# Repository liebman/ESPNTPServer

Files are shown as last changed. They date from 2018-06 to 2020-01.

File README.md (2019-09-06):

# ESPNTPServer

GPS fueled ESP8266 based NTP Server



[src](src) Contains the code for the NTP Server

[eagle](eagle) contains the schematic and board designs in Eagle cad.

[enclosure](enclosure) contains the STL files for the enclosure.

This is designed around [this GPS module](https://www.amazon.com/gp/product/B075DD5746/) but any module with standard NMEA output and a pult per second signal will work if you redesign the board or use an adapter.

I also used [this display module](https://www.amazon.com/gp/product/B00O2KDQBE/).  You can use others but be careful with the power polarity, I have modules where VCC and ground pins are in a different order.

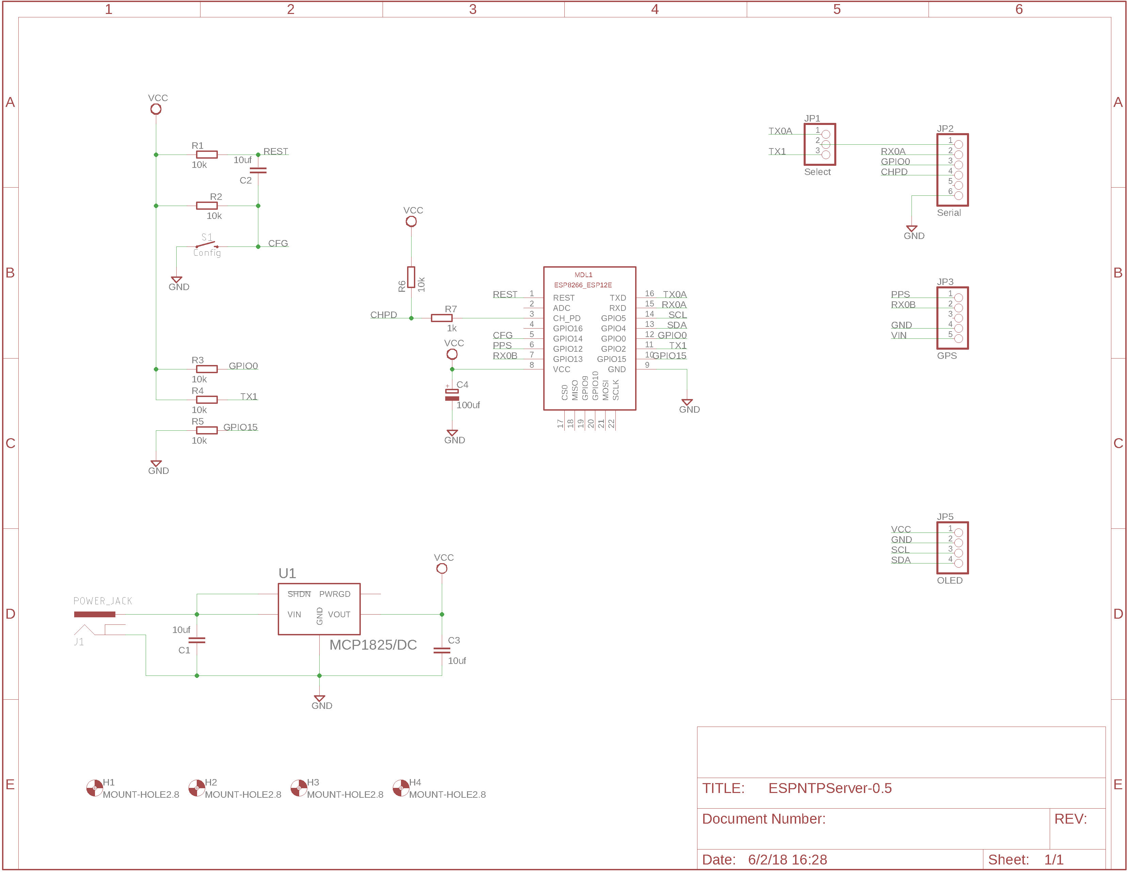
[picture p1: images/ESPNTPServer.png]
Schematic

assembly
running

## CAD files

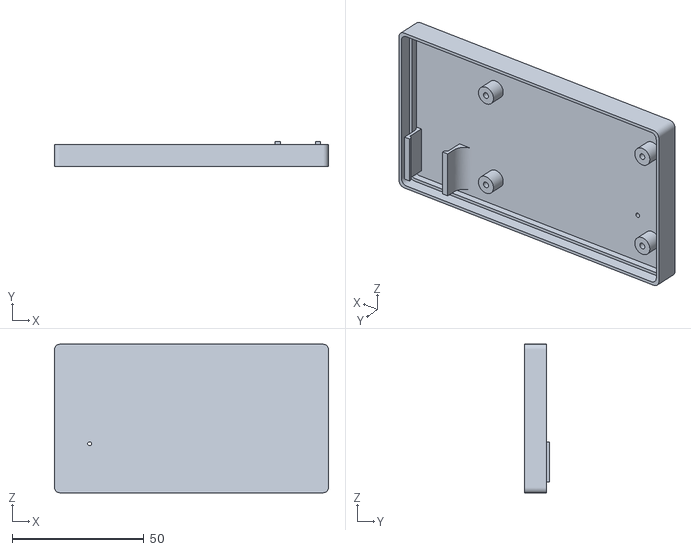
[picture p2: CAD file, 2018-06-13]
enclosure/Bottom-0.5v33.stl
103.8 x 9.30 x 56.3

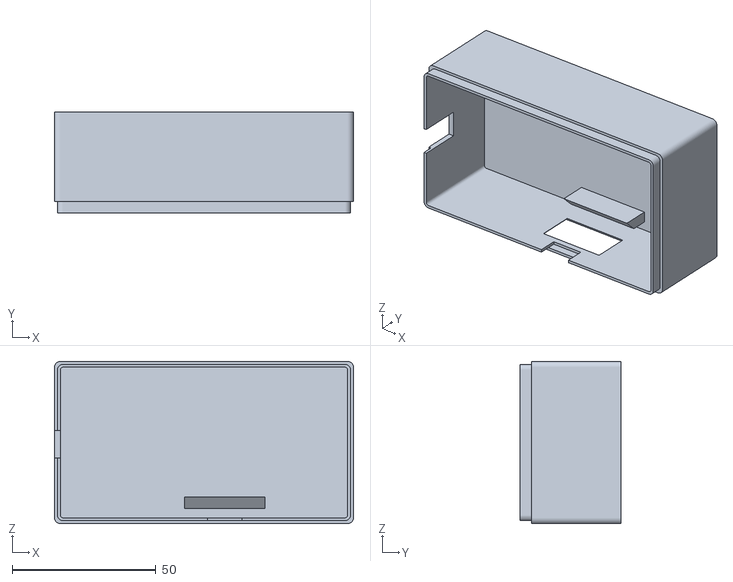
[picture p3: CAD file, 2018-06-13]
enclosure/Top-0.5v33.stl
103.8 x 35.0 x 56.3

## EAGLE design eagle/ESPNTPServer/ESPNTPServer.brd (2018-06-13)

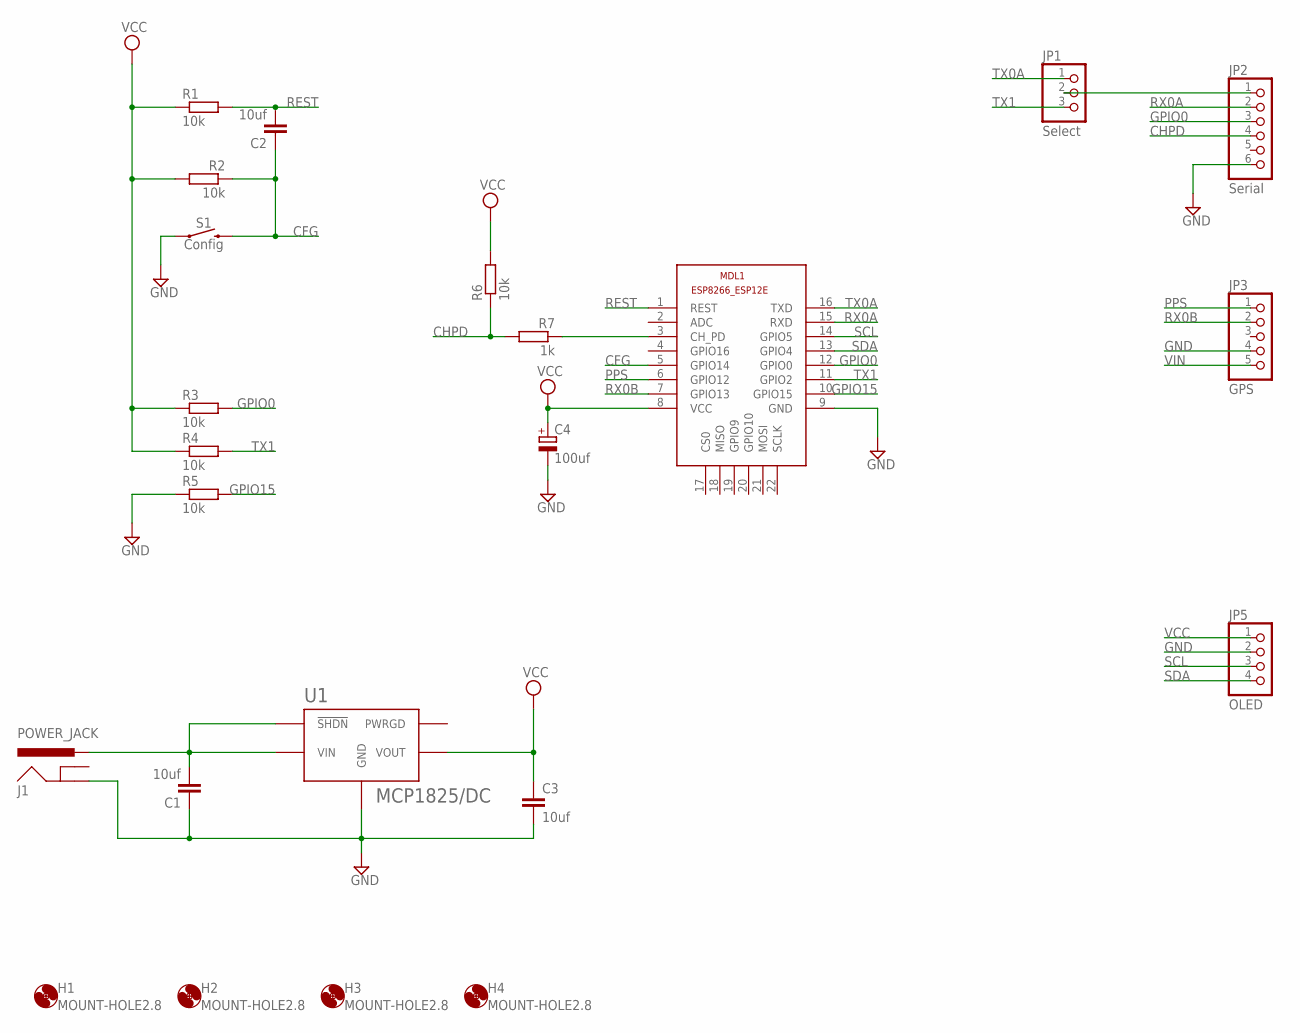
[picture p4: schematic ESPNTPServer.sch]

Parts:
C1, C2, C3: 10uf; C050-025X075
C4: 100uf; E2,5-5
H1, H2, H3, H4: MOUNT-HOLE2.8; 2,8
J1: POWER_JACK; POWER_JACK_PTH
JP1: Select; 1X03
JP2: Serial; 1X06
JP3: GPS; 1X05
JP5: OLED; 1X04
MDL1: ESP8266-12F; ESP8266-ESP12E
R1, R2, R3, R4, R5, R6: 10k; 0204V
R7: 1k; 0204V
S1: Config; TACTILE_SWITCH_PTH_6.0MM
U1: MCP1825/DC; SOT-223-5

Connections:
CFG: C2.1, MDL1.5 (GPIO14), R2.1, S1.3 (2)
CHPD: JP2.4, R6.1, R7.2
GND: C1.1, C3.2, C4.-, J1.GND, JP2.6, JP3.4, JP5.2, MDL1.9 (GND), R5.1, S1.1, U1.P$3 (GND), U1.P$6 (GND)
GPIO0: JP2.3, MDL1.12 (GPIO0), R3.2
GPIO15: MDL1.10 (GPIO15), R5.2
unnamed: JP1.2, JP2.1
unnamed: MDL1.3 (CH_PD), R7.1
PPS: JP3.1, MDL1.6 (GPIO12)
REST: C2.2, MDL1.1 (REST), R1.2
RX0A: JP2.2, MDL1.15 (RXD)
RX0B: JP3.2, MDL1.7 (GPIO13)
SCL: JP5.3, MDL1.14 (GPIO5)
SDA: JP5.4, MDL1.13 (GPIO4)
TX0A: JP1.1, MDL1.16 (TXD)
TX1: JP1.3, MDL1.11 (GPIO2), R4.2
VCC: C3.1, C4.+, JP5.1, MDL1.8 (VCC), R1.1, R2.2, R3.1, R4.1, R6.2, U1.P$4 (VOUT)
VIN: C1.2, J1.PWR, JP3.5, U1.P$1 (!SHDN), U1.P$2 (VIN)

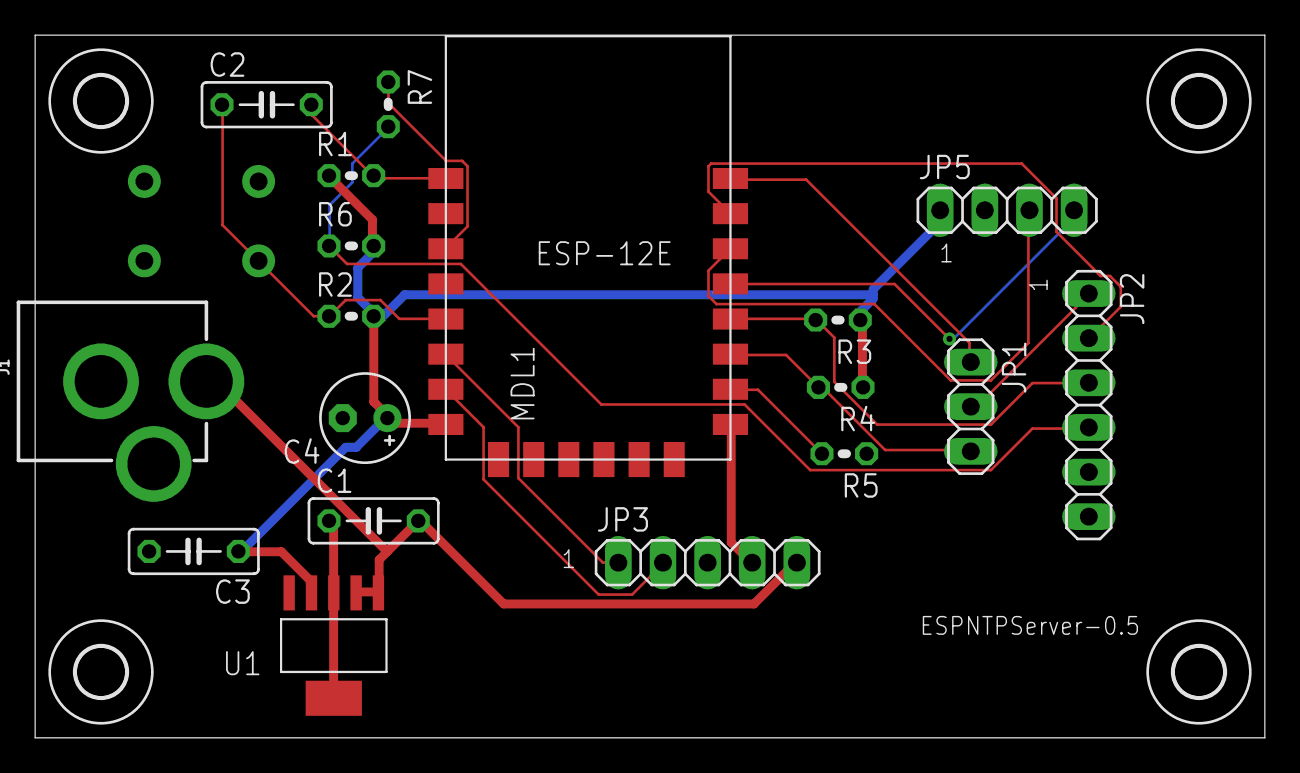
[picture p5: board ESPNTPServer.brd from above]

Board: 2 copper layers, 70.0 x 40.0 mm, 23 parts (1 on the bottom side), 17 nets.

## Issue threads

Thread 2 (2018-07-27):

Problem compiling in Arduino IDE

delinend, 2018-07-27:
Hi liebman.

I'm trying to compile you ESPNTPServer via Arduino IDE 1.8.1 (have maked an empty ESPNTPServer.ino file)
But I'm stranding on this error, in the ESPNTPServer.cpp:

sketch\ESPNTPServer.cpp: In function 'void logTimeFirst(DLogBuffer&, DLogLevel)':

ESPNTPServer.cpp:49: error: aggregate 'timeval tv' has incomplete type and cannot be defined

     struct timeval tv;

                    ^

sketch\ESPNTPServer.cpp: In function 'void loop()':

ESPNTPServer.cpp:262: error: aggregate 'timeval tv' has incomplete type and cannot be defined

     struct timeval tv;

                    ^

exit status 1
aggregate 'timeval tv' has incomplete type and cannot be defined

Best regards

delinend, 2018-07-27:
Solved the problem, by upgrading the ESP8266 Board from 2.3.0 to 2.4.1 in Arduino IDE

liebman, 2018-07-27:
Actually - this project is set up as a "sketch book"  - At some point I should update the README to describe how to set that up.  This way I can manage the exact version of the core and various libraries, they are all included as git submodules..

delinend, 2018-07-27:
Thanks for reply and great work, liebman. The ESPNTPServer project, works great on my ESP-07 module and a NEO-7M GPS with PPS output :-)

d0ugak, 2019-01-11:
I had trouble compiling this under the latest 1.8.8 Arduino IDE even after downgrading the board library version. Since the 1st post mentioned IDE [1.8.1] I downgraded to that and it compiled with no issues.

I now have this running on a Wemos D1 mini clone, One of these BLOX 6M OpenSmart GPS receivers I had laying around (https://www.dx.com/p/open-smart-serial-gps-module-for-arduino-apm2-5-flight-control-2080189) and the recommended OLED display.

Since the pin labels on a Wemos D1 mini don't translate to the actual GPIO# of the ESP8266 The following are the pins you would attach to if you build with this platform.

SCL = D1
SDA = D2
PPS = D6
TXD = D7
CFG = D5

Closed 2018-07-27.

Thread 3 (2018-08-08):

Question

bernemer, 2018-08-08:
Hi liebman,
I want to build your NTPServer.
I flashed it with the Arduino IDE 1.8.5.
In AP Mode it works but after config the wifi i get no access to the ESP.
I found it in the LAN (ping is ok) but if i connect with a Browser i get no Page.
Is this correct?
I have a NodeMCU with NEO6 conncted on TX/RX, PPS on D6(GPIO12) and 5V for the NEO6.
A Display is not connectet.
Do you have an idea whats the Problem is?

Best regards

bernemer, 2018-08-09:
Hello liebman,

i have some success.
The Display works.
After changing the TX RX to D7/D8 i received Sattelites, got Time.....
But:
every 60 seconds i have a reboot (Wifi starts) and on DOS with the command w32tm /monitor /computers: IP i get a:
ICMP: 154ms delay
NTP: error ERROR_Timeout - no reponse from server in 1000ms

The NTP Server, and PC are in the same Wifi.

Any idea?

liebman, 2018-08-09:
Are you saying it resets itself every minute?
It won't respond to NTP requests unless it thinks the GPS is stable for 120 seconds. If the display is up there is a request and a response counter.  When you send NTP requests it the request count should increase.

Can you show whats logged to serial?

bernemer, 2018-08-09:
Yes a reset ervery minute?
I get no log on the serial monitor in the IDE.
Only the ESP boot infos after using the Resetbutton with 74880 baud or ever minute a wdt reset boot info with 115200 baud.

 ets Jan 8 2013, rst cause:4, boot mode(3,6)
wdt reset
load 0x4010f000, len 1384, room 16
tail 8
chksum 0x2d
csum 0x2d
v614f7c32
~ld

Which Baudrate shoud i use?
What do i wrong?

Now i have to go to work.

liebman, 2018-08-09:
Hmm - I'll have to check the schematic I use when I get home, I'm at work now,  but I don't think can use a NodeMCU because both the GPS and the NodeMCUs USB Serial chip would be on the same UART pins.  I built my own board to work around that.  Ideally I'd have used the second UART for the GPS but on the ESP-12 modules it only has a working TX pin because the RX pin is used for the onboard flash.

liebman, 2018-08-12:
Yep.  You'll have to use a module that does not have builtin USB Serial or at least has a way for you to disconnect it from the ESP.

bernemer, 2018-08-13:
Ok. Thanks för the Information.
I am waiting for a ESP-07 and will try again.
I close the issue and give a feedback when the ESP-07 is tested.
Thanks for your support.

bernemer, 2018-08-15:
Hello Liebman,
i have the same Problem with the ESP-07.
The Display is running.
I connectet the
PPS with GPIO12 and
TX vom GPS with GPIO13
GPIO0 and 2 with 10K to High.
GPIO15 to GND.

In the Display i have 6 or 7 Sats.
I get an IP and have the right Date and Time in the Display.
The GPS is not valid.
Wenn i send with DOS w32tm /stripchart /computer:NTPIP the request count increase.
response counter still 0.
the seconds reduce from 120 but bevor i get a valid GSP the ESP reboots.

When i set the VALID_DELAY in GPS.H from 120s to 10s i became a valid GPS but every 60 second a reeboot too.

I use IDE 1.8.5 with the ESP8266 V2.4.1
Could you send me the bin file?
So i can check thats not an problem with the IDE or a wrong libery.

liebman, 2018-08-15:
Serial debug output will be on GPIO2.  If you can put a USB/Serial adapter there and watch the output - it should log when the state changes from valid to invalid, and why.  Also You should let it run for an hour or so to stabilize and insure its located where it can get a clear GPS signal.

As far as core and library versions I've actually included them as git sub-modules.  (not sure how that works on Windows) The intent is that one would set the top level directory, the one with hardware and libraries sub-directories as the Arduino Sketch folder.  Then it would show you the core and libraries in the IDE. You will probably need to make a .bat file to mimic what is done in "setup.sh" to prepare it.

bernemer, 2018-08-16:
Now i have a Log

It. starts with powering on and i stoppt after the second reboot.

 ets Jan  8 2013,rst cause:2, boot mode:(3,2)

load 0x4010f000, len 1384, room 16
tail 8
chksum 0x2d
csum 0x2d
v614f7c32
~ld
1970/01/01 00:00:00.043070 I setup Startup!
1970/01/01 00:00:00.049450 I setup Device name: ESPNTP:00e93424
1970/01/01 00:00:00.058056 I setup initializing display
1970/01/01 00:00:00.065617 I Display initializing display
1970/01/01 00:00:00.106044 I setup initializing serial for GPS
1970/01/01 00:00:00.114726 I setup initializing GPS
1970/01/01 00:00:00.166308 I Config begin: Mounting SPIFFS
1970/01/01 00:00:00.176811 I Config load: file: 'Config.json'
1970/01/01 00:00:00.185761 D Config load: parsing file contents
1970/01/01 00:00:00.195477 I Config load: config loaded!
1970/01/01 00:00:00.203170 I setup initializing wifi
1970/01/01 00:00:00.242157 I WiFiSetup connect: auto-connecting
1970/01/01 00:00:00.999999 E setup WiFi mode: 1
1970/01/01 00:00:00.999999 I setup initializing NTP
1970/01/01 00:00:00.999999 I NTP computePrecision: total:0.152298 time:0.000015 prec:-16.002743 (-16)
1970/01/01 00:00:00.999999 I loop wifi status change 0 -> 3 'CONNECTED'
1970/01/01 00:00:00.999999 W loop ip address change 0.0.0.0 -> 192.168.0.114

Exception (29):
epc1=0x40224b64 epc2=0x00000000 epc3=0x00000000 excvaddr=0x00000000 depc=0x00000000
sp: 3ffffcd0 end: 3fffffb0 offset: 01a0
3ffffe70:  3fff2208 3fff21d8 00000000 4022c193
3ffffe80:  4010500c 013d1134 3fff22cc 402286a7
3ffffe90:  3fff0b78 00000425 00000425 fffffffb
3ffffea0:  3fff20d4 00000000 3fff20d0 40224c15
3ffffeb0:  3fff22b4 3ffea154 3fff20d0 40228198
3ffffec0:  00000000 00000007 3fff32fc 40227c25
3ffffed0:  3ffea154 3ffea154 3fff20d0 402281c6
3ffffee0:  00000000 3fff20d0 3fff32fc 4022a6dc
3ffffef0:  0100a8c0 3ffec218 3ffec21e 3ffec230
3fffff00:  00000000 3fff20d0 3fff32fc 4022a72f
3fffff10:  40226044 3fff1d28 3fff21fc 40100690
3fffff20:  40253572 00000000 00000025 3fff1d24
3fffff30:  40226044 3fff1d28 3ffea0e8 40226052
3fffff40:  40104d7e 0120a89e 00000000 40226110
3fffff50:  3ffea0e8 3ffeaaa4 0120a89e 00000000
3fffff60:  40257dd4 3ffeff28 3ffeff50 60000600
3fffff70:  039bb73f 3ffeff50 3ffeff28 40257de1
3fffff80:  40257e26 3fffdab0 00000000 3fffdcb0
3fffff90:  3ffeff70 3fffdad0 3fff0c78 4021ad03
3fffffa0:  40000f49 40000f49 3fffdab0 40000f49
1970/01/01 00:00:00.043071 I setup Startup!
1970/01/01 00:00:00.049457 I setup Device name: ESPNTP:00e93424
1970/01/01 00:00:00.058063 I setup initializing display
1970/01/01 00:00:00.065639 I Display initializing display
1970/01/01 00:00:00.105928 I setup initializing serial for GPS
1970/01/01 00:00:00.114542 I setup initializing GPS
1970/01/01 00:00:00.166439 I Config begin: Mounting SPIFFS
1970/01/01 00:00:00.176978 I Config load: file: 'Config.json'
1970/01/01 00:00:00.185928 D Config load: parsing file contents
1970/01/01 00:00:00.195646 I Config load: config loaded!
1970/01/01 00:00:00.203340 I setup initializing wifi
1970/01/01 00:00:00.242277 I WiFiSetup connect: auto-connecting
1970/01/01 00:00:03.447567 E setup WiFi mode: 1
1970/01/01 00:00:03.491530 I setup initializing NTP
1970/01/01 00:00:03.643739 I NTP computePrecision: total:0.144948 time:0.000014 prec:-16.074105 (-16)
1970/01/01 00:00:03.658416 I loop wifi status change 0 -> 3 'CONNECTED'
1970/01/01 00:00:03.668370 W loop ip address change 0.0.0.0 -> 192.168.0.114
1970/01/01 00:00:11.306321 I GPS GPS valid!
1970/01/01 00:00:12.000132 I loop jitter:7 valid_count:0 valid:false gpsvalid:true numsat:8 heap:33200 valid_delay:119
1970/01/01 00:00:13.000096 I loop jitter:7 valid_count:0 valid:false gpsvalid:true numsat:8 heap:33200 valid_delay:118
1970/01/01 00:00:14.000107 I loop jitter:7 valid_count:0 valid:false gpsvalid:true numsat:8 heap:32696 valid_delay:117
1970/01/01 00:00:15.000204 I loop jitter:7 valid_count:0 valid:false gpsvalid:true numsat:8 heap:32696 valid_delay:116
1970/01/01 00:00:16.000100 I loop jitter:7 valid_count:0 valid:false gpsvalid:true numsat:8 heap:32696 valid_delay:115
1970/01/01 00:00:17.000093 I loop jitter:7 valid_count:0 valid:false gpsvalid:true numsat:8 heap:32696 valid_delay:114
1970/01/01 00:00:18.000089 I loop jitter:7 valid_count:0 valid:false gpsvalid:true numsat:8 heap:32672 valid_delay:113
1970/01/01 00:00:19.000100 I loop jitter:7 valid_count:0 valid:false gpsvalid:true numsat:8 heap:32672 valid_delay:112
1970/01/01 00:00:20.000096 I loop jitter:7 valid_count:0 valid:false gpsvalid:true numsat:8 heap:32672 valid_delay:111
1970/01/01 00:00:21.000096 I loop jitter:7 valid_count:0 valid:false gpsvalid:true numsat:7 heap:32672 valid_delay:110
2018/08/16 10:24:34.999999 I GPS adjusting seconds from 21 to 1534415074 from:'$GPRMC,102434.00,A,5006.04984,N,00838.45964,E,0.115,,160818,,,A*78'
2018/08/16 10:24:34.999999 I GPS GPS valid!
2018/08/16 10:24:34.999999 I loop jitter:7 valid_count:0 valid:false gpsvalid:true numsat:7 heap:32672 valid_delay:120
2018/08/16 10:24:34.999999 W GPS REASON: seconds adjusted!
2018/08/16 10:24:35.000099 I loop jitter:7 valid_count:0 valid:false gpsvalid:true numsat:8 heap:32672 valid_delay:119
2018/08/16 10:24:36.000101 I loop jitter:7 valid_count:0 valid:false gpsvalid:true numsat:8 heap:32672 valid_delay:118
2018/08/16 10:24:37.000107 I loop jitter:7 valid_count:0 valid:false gpsvalid:true numsat:8 heap:32672 valid_delay:117
2018/08/16 10:24:38.000097 I loop jitter:7 valid_count:0 valid:false gpsvalid:true numsat:8 heap:32672 valid_delay:116
2018/08/16 10:24:39.000102 I loop jitter:7 valid_count:0 valid:false gpsvalid:true numsat:8 heap:32672 valid_delay:115
2018/08/16 10:24:40.000097 I loop jitter:7 valid_count:0 valid:false gpsvalid:true numsat:8 heap:32672 valid_delay:114
2018/08/16 10:24:41.000098 I loop jitter:7 valid_count:0 valid:false gpsvalid:true numsat:8 heap:32672 valid_delay:113
2018/08/16 10:24:42.000098 I loop jitter:7 valid_count:0 valid:false gpsvalid:true numsat:8 heap:32672 valid_delay:112
2018/08/16 10:24:43.000102 I loop jitter:7 valid_count:0 valid:false gpsvalid:true numsat:8 heap:32672 valid_delay:111
2018/08/16 10:24:44.000097 I loop jitter:7 valid_count:0 valid:false gpsvalid:true numsat:8 heap:32672 valid_delay:110
2018/08/16 10:24:45.000103 I loop jitter:7 valid_count:0 valid:false gpsvalid:true numsat:8 heap:32672 valid_delay:109
2018/08/16 10:24:46.000100 I loop jitter:7 valid_count:0 valid:false gpsvalid:true numsat:8 heap:32672 valid_delay:108
2018/08/16 10:24:47.000105 I loop jitter:7 valid_count:0 valid:false gpsvalid:true numsat:7 heap:32672 valid_delay:107
2018/08/16 10:24:48.000099 I loop jitter:7 valid_count:0 valid:false gpsvalid:true numsat:7 heap:32672 valid_delay:106
2018/08/16 10:24:49.000097 I loop jitter:7 valid_count:0 valid:false gpsvalid:true numsat:7 heap:32672 valid_delay:105
2018/08/16 10:24:50.000099 I loop jitter:7 valid_count:0 valid:false gpsvalid:true numsat:8 heap:32672 valid_delay:104
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
liebman, 2018-08-17:
Hmm - I think you should try with the core and library versions I included as git sub-modules.  I include these as sub-modules so that I can manage the exact, sometimes patched, versions of the core and libraries.

You will need `git` and `python` installed. To do this you should run these commands from the top of the project. Note that it's possible that the syntax needs to be changed for windows.
```
git submodule update --init --recursive
cd hardware/esp8266com/esp8266/tools
python get.py
```
Then open Arduino IDE and go to Preferences or Settings (not sure what it is on windows) and change the "Sketchbook location" to the top of the project.  Next you should be able to set the board and other properties, build and flash.

bernemer, 2018-08-17:
Ok. Thanks for the help.
i will ask a friend if he had an idea how it works on windows.

bernemer, 2018-08-22:
Hello Liebman,
You are right. I had some problems with versions of libarys and Boards.
I removed all libarys and install everthing again in a new sketchbook directory.

It works !!!
Even on a NodeMCU.

Thank for the support.

liebman, 2018-08-22:
Sweet!

bernemer, 2018-08-23:
I close the issue.
Thanks

Closed 2018-08-23.

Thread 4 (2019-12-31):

Defaults to config too quickly after wifi connection loss

hemiawd, 2019-12-31:
Hi Liebman,

Great project, works great. I have encountered an issue in my environment that could possibly enhance the project for others. I am looking to use this as a highly available NTP server for my environment.

My wifi reboots weekly in the middle of the night. When this happens, the ESP detects the loss and before the wifi is reconnected the ESP goes to broadcasting it's own SSID for config mode. This takes the NTP server offline until I manually restart it. Is there a way to incorporate a configurable delay in seconds for the wifi reconnect when there is an existing config in place. Or another idea is a configurable parameter that just keeps attempting reconnects and blocks config mode from being entered unless the button is pressed.

Thanks for considering these suggestions.

liebman, 2019-12-31:
This should be doable.  I'm using WiFiManager and I know it has options to set the connect timeout.

liebman, 2019-12-31:
OK - I've created a branch `disable-auto-captive-portal` can you give that a try?  This is what "should" happen:
- the captive portal will start if the config button is held at power up/reset
- on a fresh (erased) unit the config file will not exist in SPIFFS and captive portal will start
- if it has a config file it will connect but NOT start the portal. (if its failing to connect it will delay one second and try again forever)

Let me know if this works for your use case and if so I'll merge to master.

hemiawd, 2020-01-03:
Yes, it waited out for the wifi to return and then successfully reconnected, awesome thanks. Actually rebooted 3 times and it recovered each so appears to be in great shape. All other functions appear at they were prior. When wifi comes back it does delay the 120 seconds before becoming valid again.

Closed 2020-01-04.

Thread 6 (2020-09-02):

Query

tech-freak, 2020-09-02:
Hello
thank you for such an awesome project but i have a query regarding RTC module (DS3231)
is it possible to add RTC module? i need a simple local NTP server for my projects to keep time up to date
it works very well with GPS but sometime i don't get proper signal with GPS due to bad weather and after electricity cut-off my all devices looses time :/

liebman, 2020-09-02:
While it is possible I generally include an DS3231 on any project that is that sensitive to time and use the NTP server to set it periodically. (For instance I did that [here](https://github.com/liebman/AnalogClock).

tech-freak, 2020-09-04:
Thank you for quick response but i need local NTP server(wthout gps) not for just single device

liebman, 2020-11-08:
@tech-freak an update is that I've been toying with using an ESP32+DS3231 and using the AGEOFFSET register on the DS3231 to make small adjustments to compensate for the natural drift (can be a few PPM) and to make small (less that 500us) adjustments to sync the DS3231 to the GPS.

tech-freak, 2020-11-24:
thank you for your time but i switched to ESP32+DS3231 based different project and its working fine

Closed 2020-12-26.

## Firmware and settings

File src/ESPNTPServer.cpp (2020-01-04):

/*
 * ESPNTPServer.cpp
 *
 * Copyright 2017 Christopher B. Liebman
 *
 * Licensed under the Apache License, Version 2.0 (the "License");
 * you may not use this file except in compliance with the License.
 * You may obtain a copy of the License at
 *
 *     http://www.apache.org/licenses/LICENSE-2.0
 *
 * Unless required by applicable law or agreed to in writing, software
 * distributed under the License is distributed on an "AS IS" BASIS,
 * WITHOUT WARRANTIES OR CONDITIONS OF ANY KIND, either express or implied.
 * See the License for the specific language governing permissions and
 * limitations under the License.
 *
 *
 *  Created on: Oct 29, 2017
 *      Author: liebman
 */

#include "ESPNTPServer.h"
#include "ESPNTPServerVersion.h"

#include "Log.h"
#include "DLogPrintWriter.h"
#include "DLogSyslogWriter.h"

#include "GPS.h"
#include "NTP.h"
#include "Display.h"
#include "Config.h"

DLog& dlog = DLog::getLog();
GPS gps(Serial, SYNC_PIN);
NTP ntp(gps);
Display display(gps, ntp, SDA_PIN, SCL_PIN);
Config config;

char devicename[32];

const char* SETUP_TAG = "setup";
const char* LOOP_TAG  = "loop";

void logTimeFirst(DLogBuffer& buffer, DLogLevel level)
{
    (void)level; // not used
    struct timeval tv;
    struct tm tm;
    gps.getTime(&tv);
    gmtime_r(&tv.tv_sec, &tm);

    buffer.printf(F("%04d/%02d/%02d %02d:%02d:%02d.%06ld "),
            tm.tm_year+1900,
            tm.tm_mon+1,
            tm.tm_mday,
            tm.tm_hour,
            tm.tm_min,
            tm.tm_sec,
            tv.tv_usec);
}

void processOTA(const char* ota_url, const char* ota_fp)
{
    static PROGMEM const char TAG[] = "processOTA";
    dlog.info(FPSTR(TAG), F("OTA update"));

	dlog.info(FPSTR(TAG), F("checking for OTA from: '%s'"), ota_url);
	display.message("Starting OTA");

	ESPhttpUpdate.rebootOnUpdate(false);

#ifdef USE_CERT_STORE
    (void)ota_fp; // we are using the cert store so don't need this
    CertStore certStore;
#endif
    WiFiClient *client = nullptr;

    if (strncmp(ota_url, "https:", 6) == 0)
    {
#ifdef USE_CERT_STORE
        int numCerts = certStore.initCertStore(SPIFFS, PSTR("/certs.idx"), PSTR("/certs.ar"));
        dlog.info(FPSTR(TAG), F("Number of CA certs read: %d"), numCerts);
#endif
        BearSSL::WiFiClientSecure *bear  = new BearSSL::WiFiClientSecure();
#ifdef USE_CERT_STORE
        // Integrate the cert store with this connection
        dlog.info(FPSTR(TAG), F("adding cert store to connection"));
        bear->setCertStore(&certStore);
#else
        (void)ota_fp; // not used at the moment but maybe we want to re-instate it later.
        bear->setInsecure();
#endif
        client = bear;
    }
    else
    {
        client = new WiFiClient;
    }

    t_httpUpdate_return ret = ESPhttpUpdate.update(*client, ota_url, "0.4");

	String reason = ESPhttpUpdate.getLastErrorString();

	switch(ret)
	{
		case HTTP_UPDATE_OK:
			dlog.info(FPSTR(TAG), F("OTA update OK! restarting..."));
			dlog.end();
			display.message("Success!");
			delay(10000);
			ESP.restart();
			break;

		case HTTP_UPDATE_FAILED:
			dlog.info(FPSTR(TAG), F("OTA update failed! reason:'%s'"), reason.c_str());
			display.message("FAILED!");
			delay(10000);
			break;

		case HTTP_UPDATE_NO_UPDATES:
			dlog.info(FPSTR(TAG), F("OTA no updates! reason:'%s'"), reason.c_str());
			display.message("NO Update!");
			delay(10000);
			break;

		default:
			dlog.info(FPSTR(TAG), F("OTA update WTF? unexpected return code: %d reason: '%s'"), ret, reason.c_str());
			display.message("Unknown!");
			delay(10000);
			break;
	}
}

void setup()
{
    //delay(5000); // delay for IDE to re-open serial

    //
    // Setup DLog with Serial1, set the pre function to add the date/time
    //
    Serial1.begin(76800);
    dlog.begin(new DLogPrintWriter(Serial1));
    dlog.setPreFunc(&logTimeFirst);
    //dlog.setLevel("GPS", DLogLevel::DLOG_LEVEL_DEBUG);
    dlog.setLevel("Config", DLogLevel::DLOG_LEVEL_DEBUG);

    dlog.info(SETUP_TAG, F("Startup!"));

    snprintf(devicename, sizeof(devicename), "ESPNTP:%08x", ESP.getChipId());
    dlog.info(SETUP_TAG, "Device name: %s", devicename);

    dlog.info(SETUP_TAG, F("initializing display"));
    display.begin();


    dlog.info(SETUP_TAG, F("initializing serial for GPS"));
    Serial.begin(9600);
    Serial.swap();

    dlog.info(SETUP_TAG, F("initializing GPS"));
    display.message("Starting GPS");
    gps.begin();
    display.process();

    bool force_config = false;

    config.begin();

    if (!config.load())
    {
        dlog.warning(SETUP_TAG, "no config found, forcing config portal!");
        force_config = true;
    }

    // if the reset/config button is pressed then force config
    if (digitalRead(CONFIG_PIN) == 0)
    {
        time_t start = millis();

        while (digitalRead(CONFIG_PIN) == 0)
        {
            time_t delta = millis() - start;
			if (!force_config && delta > CONFIG_DELAY)
			{
                dlog.info(SETUP_TAG, F("reset button held, forcing config!"));
                force_config = true;
				display.message("Force Config");
			}
        }
    }

#if !defined(USE_NO_WIFI)
    dlog.info(SETUP_TAG, F("initializing wifi"));
    display.message("Starting WiFi");
    WiFiSetup wifi(config, display, Serial1, false, devicename);
    wifi.connect(force_config);

    const char* syslog_host = config.getSyslogHost();
    uint16_t    syslog_port = config.getSyslogPort();
    if (syslog_host != nullptr && strlen(syslog_host) > 0 && syslog_port != 0)
    {
        dlog.info(SETUP_TAG, "enabling syslog: '%s:%u'", syslog_host, syslog_port);
        dlog.begin(new DLogSyslogWriter(syslog_host, syslog_port, devicename, ESPNTP_SERVER_VERSION));
    }

    dlog.info(SETUP_TAG, "ESP::FullVersion: %s", ESP.getFullVersion().c_str());

    const char* url = wifi.getOTAURL();
    const char* fp  = wifi.getOTAFP();
    if (fp == nullptr)
    {
    	fp = "";
    }

    if (url != nullptr)
    {
    	processOTA(url, fp);
    }

    dlog.info(SETUP_TAG, F("WiFi mode: %d"), WiFi.getMode());
    dlog.info(SETUP_TAG, F("wifi sleep mode: %d"), WiFi.getSleepMode());
#endif

    display.process();

    dlog.info(SETUP_TAG, F("initializing NTP"));
    ntp.begin();
}

void loop()
{
    static int last_wifi_status;
    static IPAddress last_ip;

    int wifi_status = WiFi.status();
    if (wifi_status != last_wifi_status)
    {
        const char* status;
        switch (wifi_status)
        {
            case WL_CONNECTED:
                status = "CONNECTED";
                break;
            case WL_NO_SSID_AVAIL:
                status = "NO_SSID";
                break;
            case WL_CONNECT_FAILED:
                status = "FAILED";
                break;
            case WL_IDLE_STATUS:
                status = "IDLE";
                break;
            case WL_DISCONNECTED:
                status = "DISCONNECTED";
                break;
            default:
                status = "<UNKNOWN>";
                break;
        }
        dlog.info(LOOP_TAG, F("wifi status change %d -> %d '%s'"), last_wifi_status, wifi_status, status);
        last_wifi_status = wifi_status;
    }

    IPAddress ip = WiFi.localIP();
    if (ip != last_ip)
    {
        dlog.warning(LOOP_TAG, F("ip address change %s -> %s"), last_ip.toString().c_str(), ip.toString().c_str());
        if (ip == IPAddress(0,0,0,0))
        {
            dlog.error(LOOP_TAG, F("lost connectivity!  Resetting!"));
            ESP.reset();
            delay(10000);
        }
        last_ip = ip;
    }

    gps.process();

    static time_t last_seconds;
    struct timeval tv;
    gps.getTime(&tv);

    if (tv.tv_sec != last_seconds)
    {
        if (tv.tv_sec != last_seconds && ((tv.tv_sec % 300) == 0 || gps.getValidDelay()))
        {
            dlog.info("loop", F("jitter:%lu valid_count:%lu valid:%s gpsvalid:%s numsat:%d heap:%ld valid_delay:%d"),
                    gps.getJitter(),
                    gps.getValidCount(),
                    gps.isValid() ? "true" : "false",
                    gps.isGPSValid() ? "true" : "false",
                    gps.getSatelliteCount(),
                    ESP.getFreeHeap(),
                    gps.getValidDelay());
        }

        if (tv.tv_sec < last_seconds)
        {
            dlog.warning(LOOP_TAG, F("OOPS: time went backwards: last:%lu now:%lu delta:%ld"), last_seconds, tv.tv_sec, tv.tv_sec-last_seconds);
        }

        display.process();
    }

    last_seconds = tv.tv_sec;
}

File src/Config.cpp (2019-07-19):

/*
 * Config.cpp
 *
 *  Created on: Jun 10, 2018
 *      Author: chris.l
 */

#include "Config.h"
#include "FS.h"
#include "Log.h"
#include "ArduinoJson.h"

static const char* TAG = "Config";
static const char* CONFIG_FILE = "/Config.json";


Config::Config() : _syslog_host(), _syslog_port(0)
{
}

Config::~Config()
{
}

bool Config::begin()
{
    dlog.info(TAG, "begin: Mounting SPIFFS");

    if (!SPIFFS.begin())
    {
        dlog.warning(TAG, "begin: Formatting SPIFFS!!!!!");
        if (SPIFFS.format())
        {
            dlog.error(TAG, "begin: SPIFFS format failed!");
            return false;
        }
        dlog.info(TAG, "begin: mounting SPIFFS after format!");
        if (!SPIFFS.begin())
        {
            dlog.error(TAG, "begin: SPIFFS mount failed!!!!");
            return false;
        }
    }

    dlog.info(TAG, "begin scanning SPIFFS files");
    Dir dir = SPIFFS.openDir("");
    while (dir.next())
    {
        File f = dir.openFile("r");
        dlog.info(TAG, "begin: file: '%s' size %d", dir.fileName().c_str(), f.size());
    }
    return true;
}

bool Config::load()
{
    dlog.info(TAG, "load: file: '%s'", CONFIG_FILE);

    if (!SPIFFS.exists(CONFIG_FILE))
    {
        dlog.warning(TAG, "load: config file does not exist!");
        return false;
    }

    File f = SPIFFS.open(CONFIG_FILE, "r");
    if (!f)
    {
        dlog.error(TAG, "load: failed to open config file!");
        return false;
    }

    StaticJsonBuffer<512> buffer;

    dlog.debug(TAG, "load: parsing file contents");
    JsonObject& root = buffer.parseObject(f);
    f.close();

    if (!root.success())
    {
        dlog.error(TAG, "load: fails to parse file!");
        return false;
    }

    strlcpy(_syslog_host, root["syslogHost"]|"", sizeof(_syslog_host));
    _syslog_port = root["syslogPort"] | 0;

    dlog.info(TAG, "load: config loaded!");
    return true;
}

void Config::save()
{
    dlog.info(TAG, "save: file: '%s'", CONFIG_FILE);

    File f = SPIFFS.open(CONFIG_FILE, "w");

    StaticJsonBuffer<512> buffer;
    JsonObject& root = buffer.createObject();

    root["syslogHost"] = _syslog_host;
    root["syslogPort"] = _syslog_port;

    root.printTo(f);
    f.close();

    dlog.info(TAG, "save: config saved");
}

const char* Config::getSyslogHost()
{
    return _syslog_host;
}

void Config::setSyslogHost(const char* host)
{
    strlcpy(_syslog_host, host, sizeof(_syslog_host));
}

uint16_t Config::getSyslogPort()
{
    return _syslog_port;
}

void Config::setSyslogPort(uint16_t port)
{
    _syslog_port = port;
}

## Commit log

2017-11-05 Switch to using micros() insteam of ESP.getCycleCount()
2017-11-11 switch to adafruit ultimate GPS, drop all the DS3231 rtc junk
2018-01-28 added esp32-snippets as submodule, added special component.mk to only grap the u8g2 hooks
2018-03-03 switched back to esp8266 and use Serial1 for debug output and Serial for GPS
2018-03-03 missed update logging change for WireUtils
    [WireUtils.cpp]
2018-03-12 Switch to use DLog as dbug output
2018-05-27 minor changes - invert display due to current hardware layout mistake
    [ESPNTPServer.cpp, ESPNTPServer.h]
2018-06-13 Reorg (#1)
    * reorg to include core and librany deps in project using submodules
    * added script to insure submodules and such are setup
    * added OTA update support and started on syslog logging
    * added syslog logging support & Config saving via SPIFFS/Json file
    * start travis builds
    * DebugLevel
    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
    [Bottom-0.5v33.stl, ESPNTPServer.brd, ESPNTPServer.sch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]
2018-06-17 cleanup syslog & devicename
2019-07-19 add support for ssl certificate bundle with bleading edge esp8266 Arduino core
2020-01-04 Disable auto captive portal when configuration exists (#5)
    * only bring up the config portal if there is no config file or
    config button is held
    * use slightly older version of WiFiManager
